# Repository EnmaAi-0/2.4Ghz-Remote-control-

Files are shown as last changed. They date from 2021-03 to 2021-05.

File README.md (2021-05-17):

# 2.4Ghz-Remote-control-
这是一个基于MM32SPIN27芯片制作的SI24R1遥控设备，可以与逐飞科技的无线串口模块直接通讯。可以在不改变原PCB的情况下远程控制智能车，包括方向，参数等（需要二次开发）。
代码部分只包含基础的通讯，AD包含全套原理图，PCB。
PCB 10 X 10以内更方便嘉立创白嫖 |ू･ω･` )

1.PCB缺陷:  PCB直接使用了NRF贴片模块，不包含PA，因此通讯范围受限，建议修改为带PA的NRF模块（已经改进，使用带PA的NRF,通讯距离更远）

2.代码缺陷： 代码方面只包含基本通讯，理论可以做到远程调参，上位机等，有待进一步完善。。

##推荐搭配v1.1使用
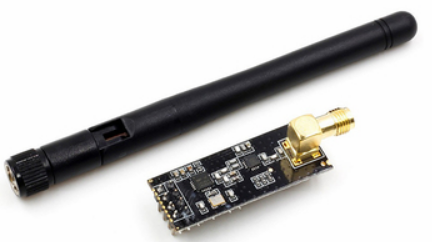
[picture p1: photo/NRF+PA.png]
##

##PCB效果图
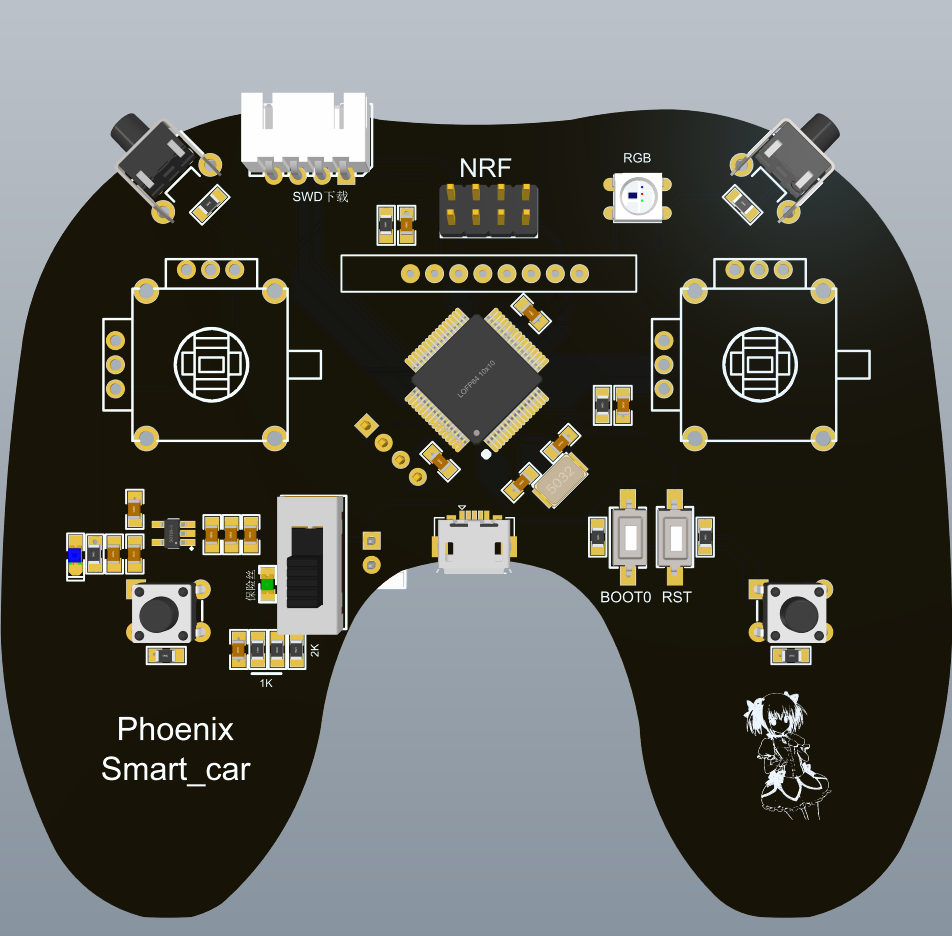
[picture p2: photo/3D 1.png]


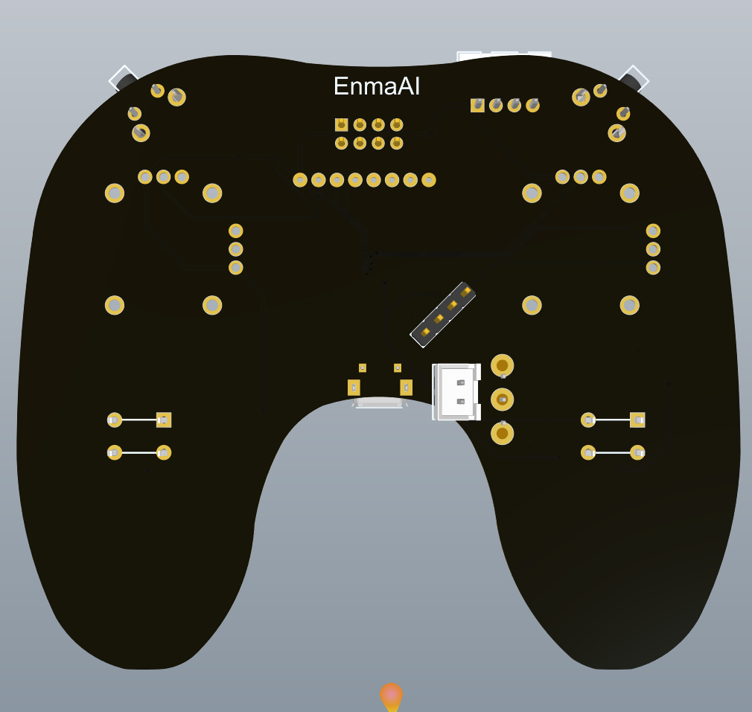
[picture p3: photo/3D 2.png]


##实物图
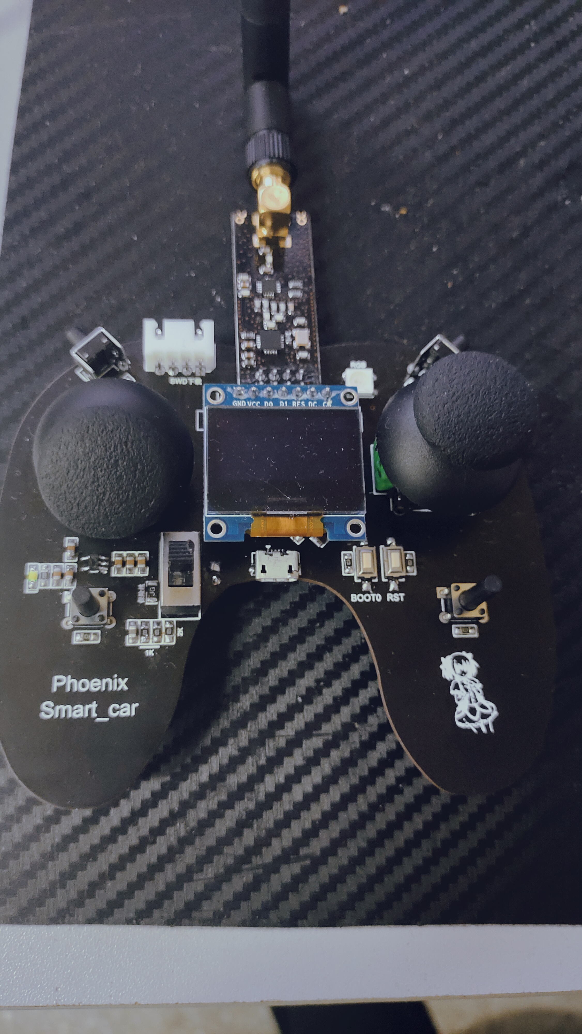
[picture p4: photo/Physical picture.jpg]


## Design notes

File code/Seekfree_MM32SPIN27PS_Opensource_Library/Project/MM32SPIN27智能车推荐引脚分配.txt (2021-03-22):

总钻风/小钻风摄像头
TXD			PC05 <单片机的 UART2 RX>
RXD			PC04 <单片机的 UART2 TX>
PLCK		PD06
VSYNC		PD07
DATA		PB00-PB07

两个电机	4路PWM TIM2
TIM2_CH1	PA11
TIM2_CH2	PA12
TIM2_CH3	PC09
TIM2_CH4	PB11

两个编码器 两路正交解码 TIM1/8
TIM1_ENC1	PA08
TIM1_ENC2	PA01
TIM8_ENC1	PC00
TIM8_ENC2	PC01

OLED/TFT1.8/IPS114屏幕
SCL/D0		PC11
SDA/D1		PC12
RST			PC13
DC			PC14
CS			PC15

陀螺仪 ICM20602/MPU6050
SCL/SPC		PD03
SDA/SDI		PD04
SAO/SDO		PD05
CS			PD02

无线转串口模块/调试下载接口串口<复用>
TX			PA09
RX			PA10
RTS			PB12

ADC输入	可用作电磁或红孩儿CCD
PA00		ADC1-CH0
PA02		ADC1-CH2
PA03		ADC1-CH3
PA05		ADC1/2-CH5
PA06		ADC1/2-CH6
PA07		ADC1/2-CH7
PB10		ADC1/2-CH11
PB13		ADC2-CH3

红孩儿CCD的时钟信号
CLK			PC02
SI			PC03
ADC2-CH2	PB14
ADC2-CH1	PB15

有来有去模块 两个接口
EN/RX		PB08
EN/RX		PB09

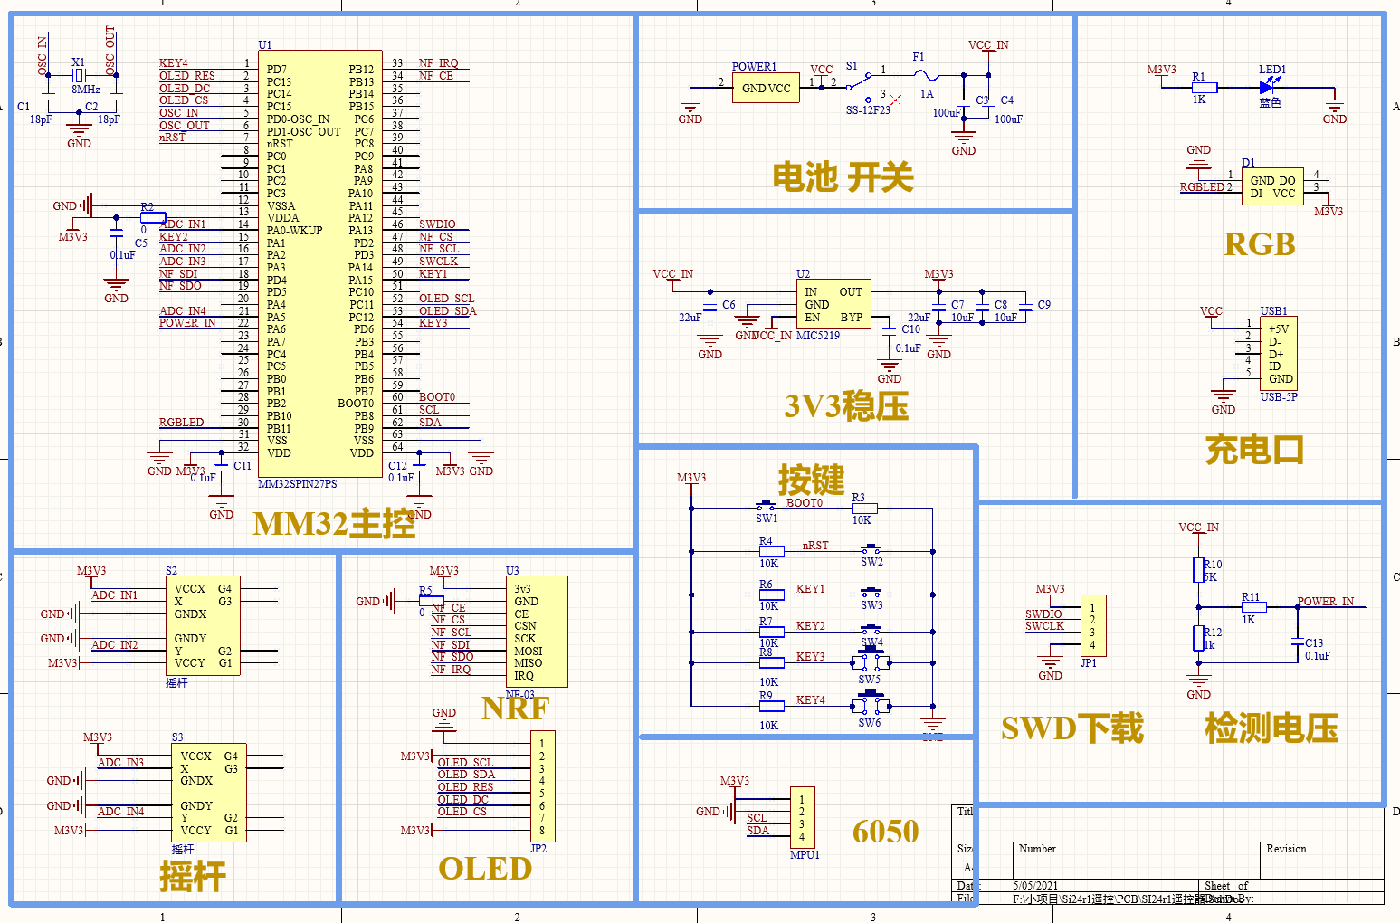
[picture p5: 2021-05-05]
photo/YLT.png

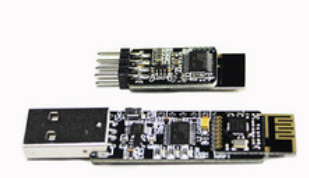
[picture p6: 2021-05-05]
photo/seekfree.png

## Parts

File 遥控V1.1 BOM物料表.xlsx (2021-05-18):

Comment | Description | Designator | Footprint | LibRef | Quantity | 立创不容易买到的器件链接
18pF | 贴片电容 | C1, C2 | C 0805_M | C | 2
100uF | 贴片电容 | C3, C4 | C 0805_M | C | 2
0.1uF | 贴片电容 | C5, C10, C11, C12, C13 | C 0805_M | C | 5
22uF | 贴片电容 | C6, C7 | C 0805_M | C | 2
10uF | 贴片电容 | C8, C9 | C 0805_M | C | 2
ws2812 | RGB灯珠 | D1 | RGB_LED_5050 | P923D | 1
1A | 贴片保险丝 | F1 | FU 0805 | FU | 1
HDR-1X4 | 4P接插件 | JP1 | XH2.54-WI-4P | Header 4 | 1
HDR-1X8 | 8P接插件 | JP2 | IPS | Header 8 | 1
Header 4X2 | 4*2P 外接NRF | JP3 | HDR2.54-LI-2x4P | Header 4X2 | 1 | https://item.taobao.com/item.htm?spm=a1z09.2.0.0.40142e8dV6LF4G&id=574454639271&_u=i3pq192hbe14
蓝色 | 贴片LED | LED1 | LED 0805B | LED-SMD | 1
HDR-1X4 | 4P接插件 | MPU1 | HDR2.54-LI-4P | Header 4 | 1
 | 外接电池 | POWER1 |  | 接电池用 | 1 | https://item.taobao.com/item.htm?spm=a1z09.2.0.0.40142e8dV6LF4G&id=613514592021&_u=i3pq192h6e9a
Res2 | Resistor | R1, R10, R11, R12 | R 0805_M | Res2 | 4
0欧电阻 |  | R2, R5 | R 0805_M | RES | 2
10K |  | R3, R4, R6, R7, R8, R9 | R 0805_M | RES | 6
SS-12F23 | 1路波动开关 | S1 | SS-12D10 | SSW-1P | 1
摇杆 |  | S2, S3 | 3D161摇杆 | 摇杆 | 2 | https://detail.tmall.com/item.htm?id=539017631913&spm=a1z09.2.0.0.40142e8dV6LF4G&_u=i3pq192h1a35
3x6x5 | 3x6轻触开关 | SW1, SW2 | TSW SMD-3*6*2.5 | TSW 3x6 | 2
6x6x5 | 侧按直插6x6轻触开关 | SW3, SW4 | TSW DIP-6*6*7_V | TSW DIP-6x6_V | 2 | https://item.taobao.com/item.htm?spm=a1z09.2.0.0.40142e8dV6LF4G&id=557056221871&_u=i3pq192hf794
6x6x5 | 直插6x6轻触开关 | SW5, SW6 | TSW DIP-6*6*6 | TSW DIP-6x6 | 2 | https://item.taobao.com/item.htm?spm=a1z09.2.0.0.40142e8dV6LF4G&id=556956143399&_u=i3pq192h781d
MM32SPIN27PS | 灵动M0主控 | U1 | LQFP64 10x10_M | MM32SPIN27PS | 1
MIC5219 | 3V3稳压 | U2 | SOT23-5M | MIC5219 | 1
USB-5P | 微型USB母座（给电池充电） | USB1 | USB-MICRO_A | USB-5P | 1
8MHz | 2脚无源脚晶振 | X1 | OSC 5032-2P | XTAL-2P | 1

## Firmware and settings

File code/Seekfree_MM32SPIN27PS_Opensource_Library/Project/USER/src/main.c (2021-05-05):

/*********************************************************************************************************************
* COPYRIGHT NOTICE
* Copyright (c) 2019,逐飞科技
* All rights reserved.
* 技术讨论QQ群：一群：179029047(已满)  二群：244861897
*
* 以下所有内容版权均属逐飞科技所有，未经允许不得用于商业用途，
* 欢迎各位使用并传播本程序，修改内容时必须保留逐飞科技的版权声明。
*
* @file				main
* @company			成都逐飞科技有限公司
* @author			逐飞科技(QQ3184284598)
* @version			查看doc内version文件 版本说明
* @Software			IAR 8.3 or MDK 5.24
* @Target core		MM32SPIN2XPs
* @Taobao			https://seekfree.taobao.com/
* @date				2020-11-23
********************************************************************************************************************/

#include "headfile.h"

//		直接兼容逐飞科技的无线串口模块
//使用时只需更改 NRF_RF_Addr 的地址即可通讯
int main(void)
{
	board_init(true);																// 初始化 debug 输出串口
	system_init();

	while(1)
	{
		
		Loop_Run();

	}
}
// **************************** 代码区域 ****************************

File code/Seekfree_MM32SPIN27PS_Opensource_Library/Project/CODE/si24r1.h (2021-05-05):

#ifndef _SI24R1_H_
#define _SI24R1_H_

#include "common.h"
#include "headfile.h"

//-----------------------SI24R1配置-------------------------//
#define NRF_RF_CH       100					// RF射频通道 0~125
#define	NRF_ADDR_WIDTH  5                   // RF地址宽度 1~5byte
#define NRF_DATA_WIDTH  31                  // RF数据宽度 1~32byte


//-----------------------SI24R1引脚配置-------------------------//
#define NRF_SPI_NUM				SPI_1
#define NRF_CE_PIN          	B13
#define NRF_CSN_PIN         	D2
#define NRF_SCK_PIN         	SPI1_SCK_D03
#define NRF_MOSI_PIN        	SPI1_MOSI_D04                            
#define NRF_MISO_PIN        	SPI1_MISO_D05
#define NRF_IRQ_PIN         	B12


#define SI24R1_CS(x)		((x == 0)? (GPIO_PIN_RESET(SI24R1_CSN_PIN))  :(GPIO_PIN_SET(SI24R1_CSN_PIN)))
#define SI24R1_CE(x)		((x == 0)? (GPIO_PIN_RESET(SI24R1_CE_PIN))  :(GPIO_PIN_SET(SI24R1_CE_PIN)))

#define NRF_CE(x)   gpio_set(NRF_CE_PIN,x)
#define NRF_CSN(x)  gpio_set(NRF_CSN_PIN,x)
#define NRF_MOSI(x) gpio_set(NRF_MOSI_PIN,x)
#define NRF_SCK(x)  gpio_set(NRF_SCK_PIN,x)
#define NRF_MISO    gpio_get(NRF_MISO_PIN)
#define NRF_IRQ     gpio_get(NRF_IRQ_PIN)


// SPI命令字   SPI Commands
#define NRF_CMD_R_REGISTER          0x00    // 读寄存器             Read command and status registers
#define NRF_CMD_W_REGISTER          0x20    // 写寄存器             Write command and status registers
#define NRF_CMD_R_RX_PAYLOAD        0x61    // 读RXFIFO             Read RX-payload
#define NRF_CMD_W_TX_PAYLOAD        0xA0    // 读TXFIFO             Write TX-payload
#define NRF_CMD_FLUSH_TX            0xE1    // 清TXFIFO             Flush TX FIFO
#define NRF_CMD_FLUSH_RX            0xE2    // 清RXFIFO             Flush RX FIFO
#define NRF_CMD_REUSE_TX_PL         0xE3    // 重发TX数据           Used for a PTX device Reuse last transmitted payload.
#define NRF_CMD_R_RX_PL_WID         0x60    // 读RX数据宽           Read RX payload width for the top R_RX_PAYLOAD in the RX FIFO
#define NRF_CMD_W_ACK_PAYLOAD       0xA8    // 带ACK的数据          Write Payload to be transmitted together with ACK packet on PIPE
#define NRF_CMD_W_TX_PAYLOAD_NOACK  0xB0    // 无ACK的数据          Disables AUTOACK on this specific packet.
#define NRF_CMD_NOP                 0xFF    // 空操作"命令字        No Operation.Might be used to read the STATUS register

// SPI寄存器地址     Registers Addresses
#define NRF_REG_CONFIG              0x00    // 配置寄存器           Configuration Register
#define NRF_REG_EN_AA               0x01    // 使能自动应答         Enable ‘Auto Acknowledgment’
#define NRF_REG_EN_RXADDR           0x02    // 使能RX数据通道       Enabled RX Addresses
#define NRF_REG_SETUP_AW            0x03    // 设置地址宽度         Setup of Address Widths
#define NRF_REG_SETUP_RETR          0x04    // 设置自动重发         Setup of Automatic Retransmission
#define NRF_REG_RF_CH               0x05    // 频道设置             RF Channel
#define NRF_REG_RF_SETUP            0x06    // RF设置               RF Setup Register
#define NRF_REG_STATUS              0x07    // 状态                 Status Register
#define NRF_REG_OBSERVE_TX          0x08    // 发送监测             Transmit observe register
#define NRF_REG_RPD                 0x09    // 接收功率监测         Received Power Detector (nRF24L01+ only),Carrier Detect(nRF24L01 only)
#define NRF_REG_RX_ADDR_P0          0x0A    // 接收通道0地址        Receive address data pipe 0
#define NRF_REG_RX_ADDR_P1          0x0B    // 接收通道1地址        Receive address data pipe 1
#define NRF_REG_RX_ADDR_P2          0x0C    // 接收通道2地址        Receive address data pipe 2
#define NRF_REG_RX_ADDR_P3          0x0D    // 接收通道3地址        Receive address data pipe 3
#define NRF_REG_RX_ADDR_P4          0x0E    // 接收通道4地址        Receive address data pipe 4
#define NRF_REG_RX_ADDR_P5          0x0F    // 接收通道5地址        Receive address data pipe 5
#define NRF_REG_TX_ADDR             0x10    // 发送地址             Transmit address
#define NRF_REG_RX_PW_P0            0x11    // 接收通道0数据宽度    Number of bytes in RX payload in data pipe 0
#define NRF_REG_RX_PW_P1            0x12    // 接收通道1数据宽度    Number of bytes in RX payload in data pipe 1
#define NRF_REG_RX_PW_P2            0x13    // 接收通道2数据宽度    Number of bytes in RX payload in data pipe 2
#define NRF_REG_RX_PW_P3            0x14    // 接收通道3数据宽度    Number of bytes in RX payload in data pipe 3
#define NRF_REG_RX_PW_P4            0x15    // 接收通道4数据宽度    Number of bytes in RX payload in data pipe 4
#define NRF_REG_RX_PW_P5            0x16    // 接收通道5数据宽度    Number of bytes in RX payload in data pipe 5
#define NRF_REG_FIFO_STATUS         0x17    // FIFO状态             FIFO Status Register
#define NRF_REG_DYNPD               0x1C    // 允许动态数据包长度   Enable dynamic payload length
#define NRF_REG_FEATURE             0x1D    // 特征寄存器           Feature Register

// SPI寄存器配置     Registers Config

// 0x00 CONFIG  配置寄存器
#define NRF_RCD_RX_DR_EN            0<<6    // bit6=MASK_RX_DR=0=映射RX_DR中断(数据接收完成时IRQ输出L)
#define NRF_RCD_RX_DR_DI            1<<6    // bit6=MASK_RX_DR=1=屏蔽RX_DR中断
#define NRF_RCD_TX_DS_EN            0<<5    // bit5=MASK_TX_DR=0=映射TX_DR中断(数据接收完成时IRQ输出L)
#define NRF_RCD_TX_DS_DI            1<<5    // bit5=MASK_TX_DR=1=屏蔽TX_DR中断
#define NRF_RCD_MAX_RT_EN           0<<4    // bit4=MASK_MAX_RT=0=映射MASK_MAX_RT中断(超过重发上限时IRQ输出L)
#define NRF_RCD_MAX_RT_DI           1<<4    // bit4=MASK_MAX_RT=1=屏蔽MASK_MAX_RT中断
#define NRF_RCD_CRC_DI              0<<3    // bit3=EN_CRC=0=禁用CRC
#define NRF_RCD_CRC_EN              1<<3    // bit3=EN_CRC=1=启用CRC
#define NRF_RCD_CRC8                0<<2    // bit2=CRCO=0=CRC-8=1byte
#define NRF_RCD_CRC16               1<<2    // bit2=CRCO=1=CRC-16=2byte
#define NRF_RCD_PWR_DOWN            0<<1    // bit1=PWR_UP=0=电源关闭模式
#define NRF_RCD_PWR_UP              1<<1    // bit1=PWR_UP=1=电源开启模式
#define NRF_RCD_PRIM_PRX            1       // bit0=PRIM_RX=1=接收模式
#define NRF_RCD_PRIM_PTX            0       // bit0=PRIM_RX=0=发送模式

// 0x01 EN_AA   使能自动应答
#define NRF_RCD_ALL_PIPE_AA_DI      0       // bit5:0=000000=禁用全部通道的AA
#define NRF_RCD_PIPE5_AA_DI         0<<5    // bit5=ENAA_P5=0=禁用通道5的AA(Auto Ack自动应答)
#define NRF_RCD_PIPE5_AA_EN         1<<5    // bit5=ENAA_P5=1=启用通道5的AA
#define NRF_RCD_PIPE4_AA_DI         0<<4    // bit4=ENAA_P4=0=禁用通道4的AA
#define NRF_RCD_PIPE4_AA_EN         1<<4    // bit4=ENAA_P4=1=启用通道4的AA
#define NRF_RCD_PIPE3_AA_DI         0<<3    // bit3=ENAA_P3=0=禁用通道3的AA
#define NRF_RCD_PIPE3_AA_EN         1<<3    // bit3=ENAA_P3=1=启用通道3的AA
#define NRF_RCD_PIPE2_AA_DI         0<<2    // bit2=ENAA_P2=0=禁用通道2的AA
#define NRF_RCD_PIPE2_AA_EN         1<<2    // bit2=ENAA_P2=1=启用通道2的AA
#define NRF_RCD_PIPE1_AA_DI         0<<1    // bit1=ENAA_P1=0=禁用通道1的AA
#define NRF_RCD_PIPE1_AA_EN         1<<1    // bit1=ENAA_P1=1=启用通道1的AA
#define NRF_RCD_PIPE0_AA_DI         0       // bit0=ENAA_P0=0=禁用通道0的AA
#define NRF_RCD_PIPE0_AA_EN         1       // bit0=ENAA_P0=1=启用通道0的AA
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

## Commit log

2021-05-05 v1.0 基础功能完善
    [SI24r1遥控器.SchDoc]
2021-05-10 更新带PA的版本
    [SI24r1遥控器.SchDoc, Si24r1遥控.PrjPcb, 摇杆.SchLib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]
2021-05-17 更新实物图
2021-05-18 更新物料表
    [遥控V1.1 BOM物料表.xlsx]
2021-05-18 新BOM表
    [遥控V1.1 BOM物料表.xlsx]

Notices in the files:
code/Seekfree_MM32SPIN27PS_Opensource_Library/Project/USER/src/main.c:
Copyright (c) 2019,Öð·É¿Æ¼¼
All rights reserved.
